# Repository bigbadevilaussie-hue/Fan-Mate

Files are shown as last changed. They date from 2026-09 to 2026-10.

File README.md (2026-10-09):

# Fan-Mate

ESP32-C3 fan controller that keeps an iPhone cool on a 24/7 hotspot mount.

The iPhone is the sole internet uplink (weak signal, rural Queensland). Every byte through the network heats its cellular modem. Fan-Mate watches the router WAN traffic rate and spins a 40mm PWM fan when downloads are detected — before the phone gets hot, not after.

Current: **FW v4.50** · **Tk GUI v4.50** · **QML GUI2 v1.11** (parked)

Repo: https://github.com/bigbadevilaussie-hue/Fan-Mate

## Hardware

| Component | Pin | Notes |
|---|---|---|
| MCU | — | ESP32-C3 SuperMini |
| Thermistor (NTC) | GPIO 0 | 10k MF52AT, room temp, +6.0 offset |
| Hall sensor | GPIO 1 | A3144, phone presence |
| Fan tach | GPIO 3 | INPUT_PULLUP, IRQ |
| DS18B20 | GPIO 4 | Phone back contact |
| OLED SDA / SCL | GPIO 5 / 6 | I2C |
| Fan PWM | GPIO 7 | 25 kHz, 8-bit |
| Blue LED | GPIO 8 | onboard |
| Buzzer | GPIO 10 | LEDC channel 1 |

Shroud printed, mounted on Quad Lock adapter. Phone docked. DS18B20 in the Quad Lock socket against the case back. Fan over the camera bump, adjacent to the SoC.

## What it does

- **Network-triggered boost** — responds to router WAN traffic, not phone temp. Traffic heats the modem before the phone surface warms.
- **Rate-based gears** — target gear = `floor(net_kbps / threshold)`, clamp 0–4, with up/down hysteresis.
- **Cooldown hold** — when traffic stops, holds gear 1 until phone temp returns to the pre-boost value (or 20-min timeout).
- **Delta guard** — phone 5.1°C above room → gear 1 floor. Configurable.
- **Heat control** — four thresholds (Warm/Hot/Hotter/Critical = 33/35/37/39) with per-gear hysteresis.
- **Priority** — `max(heat, delta, boost)`.
- **Kill mode** — at Critical: fan 100%, buzzer every 30s, repeater cut. Manual re-arm.
- **Autonomous** — cools and logs whether the Mac is on or off. Sleeps when phone absent.
- **Hourly log rotation** — sealed, CRC32-verified Mac sync, Drive upload.

## Build

Arduino IDE 2.x or arduino-cli. ESP32 core **2.0.17** (2.x required — do NOT upgrade to 3.x).

Partition: `:PartitionScheme=min_spiffs` (1408 KB LittleFS).

```zsh
arduino-cli compile --fqbn esp32:esp32:esp32c3:PartitionScheme=min_spiffs --export-binaries .
# binary: build/esp32.esp32.esp32c3/fanmate.ino.bin
```

Libraries: Adafruit GFX, Adafruit BusIO, Adafruit SSD1306, OneWire, DallasTemperature, ArduinoJson.

Secrets: copy `secrets.example.h` to `secrets.h`, fill WiFi + Opal credentials.

OTA: Tk GUI menu → 📡 Update Firmware.

## GUI

**Tk GUI** (primary) — `python3 fanmate.py`. Live telemetry, Settings, Reports, DynaTune KPI board, OTA, log sync, weather, day/night theme.

**QML GUI2** (parked) — `fanmate_v2/*`. Ports frozen behaviour once firmware + Tk are stable.

**Web dashboard** — served by ESP32 at `/`. Read-only except kill-mode banner.

## Repo

https://github.com/bigbadevilaussie-hue/Fan-Mate

Related: [Bike-Mate](https://github.com/bigbadevilaussie-hue/Bike-Mate) — ESP32-C3, same OLED fork, same OTA/GitHub-upload pattern. Still on the breadboard. Fan-Mate is the reference implementation; port to Bike-Mate once Fan-Mate is stable.

## Rules

### Version bump
Every change bumps the version, before compiling:

- Firmware: `FAN_MATE_VERSION` in `Config.h`
- Tk: `GUI_VERSION` in `fanmate/config.py`
- QML: `guiVersion` in `fanmate_v2/qml/Main.qml`

If the bump lands after the compile, the firmware reports the old version and log filenames use the old prefix.

### Behaviour
Never mention sleep, rest, breaks, session length, time of day, or "good morning/evening". Do not suggest stopping. Do not wrap up sessions unless asked. Just answer the question and keep working.

### Patching
Write each patch as a Python script using a heredoc into `/tmp/patch.py`, then run it in the same paste:

```zsh
cat > /tmp/patch.py <<'PYEOF'
import os, shutil
...
PYEOF
python3 /tmp/patch.py
```

- Always back up first with `shutil.copy2`.
- Always end with a verification print.
- Patch and run in one block.
- Never paste standalone multi-line shell that edits files.

### Working style
- Don't guess. Read the screenshot, read the file, read the log. If unsure, say unsure.
- Don't score, rate, or editorialise unless asked.
- Don't reference time of day, session length, or wrap-up language.
- One change at a time unless asked for more. Short replies.

### Naming
GUI = Tk (`fanmate/*.py`). GUI2 = QML (`fanmate_v2/*`). Web = `WebPage.h` (needs flash). Firmware = `.cpp`/`.h`/`.ino`.

### Handoff — read this first

The README alone is not enough. Before changing anything, ask for:

- repo.txt, dump.txt, firmware_dump.txt — three dumps written to Desktop. Ask how they were produced.
- ls ~/Documents/Arduino/libraries/Adafruit_SSD1306_72x40/ — custom fork, not in the repo, required to compile.
- git ls-files secrets.h — if it prints anything, credentials in that file are tracked and need rotating.
- Which GUI is the live target. README says QML is parked; recent commits say otherwise. Ask, do not assume.
- If touching DynaTune or log analysis: one log-*.csv and dynatune-history.csv from ~/Documents/FanMate_logs/.

Do not touch code until all three dumps and the library listing are in hand.

### Gotchas
- Catalina mDNS slow. Use IP `192.168.8.242`, not `.local`.
- `WiFi.RSSI()` returns 0 when disconnected.
- `server.handleClient()` doesn't work here. Use `server_loop()`.
- NVS keys ≤15 chars. Longer keys silently fail.
- Fan fails safe to 100% (bootloader leaves GPIO 7 undriven).
- QML Column + anchors don't mix. Use `TapHandler` for clicks inside Columns.

## Known issues

**DynaTune**
- `_test_boost` infers gear from fan %, which fails during night mode (fan 75% reads as gear 3 when the firmware commanded gear 4). Fix: read the row timestamp, check against the night window, adjust the fan→gear mapping.
- `_test_heat_gears` compares `temp.gear1` against `avg_room + delta_trigger`. Recommendation text hardcodes `boost.on_hold 4 → 2` regardless of the current `on_hold` value. Fix: read the current setting and only suggest a change if it differs.

**Firmware**
- Cooldown margin. Currently `cold_temp + 0.3` releases the fan before residual modem heat arrives, so phone can creep up ~1°C post-download. Consider `COOLDOWN_MARGIN_C = 1.5` in AutoBoost.cpp, or make it configurable via NVS (`cooldown.margin`, Settings field).
- Double-Apply in the same minute still creates a duplicate seal name (cosmetic; collision suffix `-2` handles it, GitHub upload succeeds on second attempt with SHA).

**GUI**
- Settings dialog reads `state.latest_config` which refreshes every 5 min. Can show stale values right after an Apply.

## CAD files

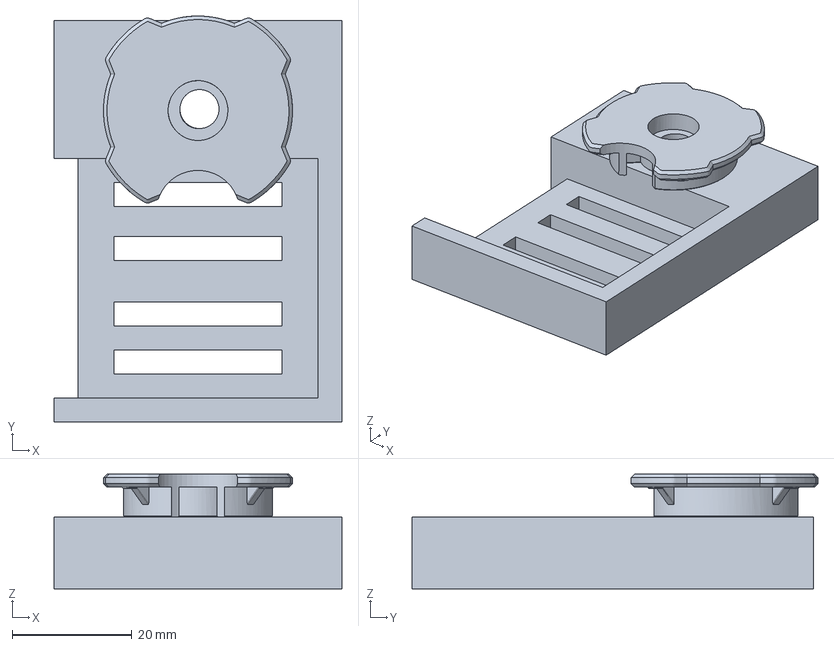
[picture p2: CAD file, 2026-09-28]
3mf/phone-assembly.3mf
48.0 x 67.8 x 19.2 mm

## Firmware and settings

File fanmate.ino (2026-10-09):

#include "Config.h"
#include "Settings.h"
#include "FanController.h"
#include "DisplayManager.h"
#include "WiFiManager.h"
#include "WebServer.h"
#include "OpalClient.h"
#include "AutoBoost.h"
#include "Logging.h"
#include "WeatherClient.h"
#include "SerialBuffer.h"
#include "Songs.h"

#include <esp_arduino_version.h>

#if ESP_ARDUINO_VERSION_MAJOR >= 3
#error "Fan-Mate requires Arduino ESP32 core 2.x (2.0.17)"
#endif

float currentTemp  = 0.0;
int   fanPct       = 0;
int   fanRPM       = 0;
int   alertState   = 0;
bool  phonePresent = false;

volatile bool otaInProgress = false;

SystemState   sys_state = STATE_ACTIVE;
static unsigned long sleep_start_ms = 0;
bool          have_baseline = false;
uint64_t      last_rx       = 0;
unsigned long last_tick     = 0;

#define WEB_HIST_LEN 60
float webTempHist[WEB_HIST_LEN] = {0};
float webNetHist[WEB_HIST_LEN]  = {0};
float webRpmHist[WEB_HIST_LEN]  = {0};
int   webHistIdx = 0;

void enter_sleep() {
    log_print("[SLEEP] phone absent — entering sleep\n");
    log_write_event("SLEEP");
    log_flush_seal();
    sys_state = STATE_LIGHT_SLEEP;
    sleep_start_ms = millis();
    silenceFanAndAlerts();
    auto_boost_release();
    opal_pause();
    clearDisplay();
    digitalWrite(LED_PIN, LOW);
    playNokiaSong();
    log_print("[SLEEP] entered\n");
}

void exit_sleep() {
    sys_state = STATE_ACTIVE;
    log_resume();
    log_write_event("WAKE");
    have_baseline = false;
    last_rx = 0;
    last_tick = millis() - 15000;
    opal_resume();
    wakeDisplay();
    digitalWrite(LED_PIN, HIGH);
    playNokiaSong();
    log_print("[SLEEP] awake\n");
}

void setup() {
    Serial.begin(115200);
    delay(500);

    serial_buf_init();

    Serial.println();
    Serial.println("================================");
    Serial.printf ("  Fan-Mate V%s\n", FAN_MATE_VERSION);
    Serial.printf ("  Build: %s %s\n", __DATE__, __TIME__);
    Serial.println("  Chip:  ESP32-C3");
    Serial.println("  Mode:  HTTP only");
    Serial.println("================================");

    pinMode(LED_PIN, OUTPUT);
    digitalWrite(LED_PIN, HIGH);

    setenv("TZ", "AEST-10", 1);
    tzset();

    settings_load();
    weather_init();
    initHardware();

    Serial.println("[BOOT] waiting for DS18B20...");
    for (int i = 0; i < 20; i++) {
        float t = 0.0f;
        readDS18B20(t);
        if (t > -50.0f && t < 100.0f && t != 0.0f) {
            currentTemp = t;
            log_print("[BOOT] DS18B20 first: %.1f C\n", t);
            break;
        }
        delay(500);
    }
    initDisplay();
    log_init();
    log_write_reset_reason();

    drawSplashScreen();
    delay(5000);

    wifi_setup();

    // v4.29: wait up to 3s for LAN clock before boot recovery
    {
        unsigned long wait_start = millis();
        while (!clock_synced() && millis() - wait_start < 5000) {
            wifi_loop();
            clock_sync();
            delay(200);
        }
        log_print("[BOOT] clock wait done (%s)\n",
                  clock_synced() ? "synced" : "timeout");
    }

    log_boot_recovery();

    log_print("[BOOT] Fan-Mate V%s ready\n", FAN_MATE_VERSION);
}

float lastNetKbps = 0.0;

static void tick_15s() {
    uint64_t rx_now = 0;
    bool opal_ok = opal_poll(rx_now);

    float kbps = 0.0f;
    if (opal_ok) {
        if (have_baseline && rx_now >= last_rx) {
            uint64_t delta = rx_now - last_rx;
            kbps = (delta / 15.0f) / 1024.0f;
        } else {
            have_baseline = true;
        }
        last_rx = rx_now;
    } else {
        // Router unreachable — keep last known rate, skip boost update
        kbps = lastNetKbps;
    }

    static float peak_hist[3] = {0, 0, 0};
    static int   peak_idx = 0;
    peak_hist[peak_idx] = kbps;
    peak_idx = (peak_idx + 1) % 3;

    float kbps_smooth = peak_hist[0];
    if (peak_hist[1] > kbps_smooth) kbps_smooth = peak_hist[1];
    if (peak_hist[2] > kbps_smooth) kbps_smooth = peak_hist[2];

    if (kbps_smooth > 10240.0f) kbps_smooth = lastNetKbps;
    lastNetKbps = kbps_smooth;

    webTempHist[webHistIdx] = currentTemp;
    webNetHist[webHistIdx]  = kbps_smooth;
    webRpmHist[webHistIdx]  = (float)fanRPM;
    webHistIdx = (webHistIdx + 1) % WEB_HIST_LEN;

    auto_boost_update(kbps_smooth, currentTemp, opal_ok);

    if (currentTemp > 0.0) {
        log_write(currentTemp, kbps_smooth,
                  auto_boost_gear(),
                  fanPct, fanRPM);
    }

    log_rotate_check();
    log_check_full();

#if DEBUG_VERBOSE
    log_print("[TICK] temp=%.1f fan=%d%% net=%.1f KB/s boost=%d rpm=%d\n",
              currentTemp, fanPct, kbps_smooth,
              auto_boost_gear(), fanRPM);
#endif
}

void loop() {
  server_loop();
    static unsigned long lastOLED     = 0;
    static bool          server_ready = false;

    unsigned long now = millis();

    wifi_loop();
    clock_sync();
    weather_loop();
    if (wifi_connected() && !server_ready) {
        server_setup();
        opal_init();
        auto_boost_init();
        server_ready = true;
    }
    if (server_ready) {
        server_loop();
    }

    updatePhoneDetection();
    updateTach();
    readDS18B20(currentTemp);

    bool phone_now = phonePresent;

    if (sys_state == STATE_ACTIVE) {
        if (!phone_now &&
            phone_absent_since > 0 &&
            now - phone_absent_since >= PHONE_SLEEP_DELAY_MS) {
            enter_sleep();
        }
    } else if (sys_state == STATE_LIGHT_SLEEP) {
        if (phone_now &&
                   phone_present_since > 0 &&
                   now - phone_present_since >= PHONE_WAKE_DELAY_MS) {
            exit_sleep();
        }
    }

    beep_once_update();

    if (sys_state == STATE_ACTIVE) {
        updateFanAndAlerts(currentTemp, fanPct, fanRPM, alertState, phonePresent);

        if (now - lastOLED >= 500 && !otaInProgress) {
            lastOLED = now;
            updateDisplay(currentTemp, fanPct, fanRPM, alertState, phonePresent);
        }

        if (server_ready && now - last_tick >= 15000) {
            last_tick = now;
            tick_15s();
        }
    }
}

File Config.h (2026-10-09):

#ifndef CONFIG_H
#define CONFIG_H

#if __has_include("secrets.h")
    #include "secrets.h"
#else
    #warning "secrets.h not found - copy secrets.example.h to secrets.h"
    #include "secrets.example.h"
#endif

// v4.28 network resilience
#define OPAL_HTTP_TIMEOUT_MS 400
#define OPAL_RSSI_FLOOR -70
#define NTP_SYNC_COOLDOWN_MS 60000
#define CLOCK_SYNC_INTERVAL_MS  60000UL
#define CLOCK_HTTP_TIMEOUT_MS   3000

enum SystemState {
    STATE_ACTIVE      = 0,
    STATE_LIGHT_SLEEP = 1,
};
extern SystemState   sys_state;
extern unsigned long phone_absent_since;

#define FAN_MATE_VERSION "4.60"

#define DEBUG_VERBOSE 0

#define SDA_PIN          5
#define SCL_PIN          6
#define FAN_PWM_PIN      7
#define LED_PIN          8
#define BUZZER_PIN       10
#define BUZZER_TONE_HZ   2000
#define TACH_PIN         3
#define DS18B20_PIN      4
#define PHONE_SENSE_PIN  1
// v4.60: hall sensor temporarily disabled (shorted VCC/GND)
// Set to 1 once the wiring is fixed. When 0, phonePresent is
// forced true so the device never enters light sleep.
#define HALL_SENSOR_ENABLED 0
#define NTC_PIN          0

#define PWM_FREQ      25000
#define PWM_RES       8

#define FAN_STALL_ENABLED 1


#define WARNING_BEEPS       2
#define WARNING_BEEP_MS     150
#define WARNING_GAP_MS      200
#define WARNING_INTERVAL_MS 120000

#define PANIC_BEEPS       5
#define PANIC_BEEP_MS     200
#define PANIC_GAP_MS      200
#define PANIC_INTERVAL_MS 120000

#define KILL_BEEPS       3
#define KILL_BEEP_MS     200
#define KILL_GAP_MS      200
#define KILL_INTERVAL_MS 30000

#define HTTP_PORT                80
#define WIFI_CONNECT_TIMEOUT_MS  15000
#define WIFI_RETRY_INTERVAL_MS   30000

#define SERIAL_BUF_LINES        20
#define PHONE_SLEEP_DELAY_MS    30000UL
#define PHONE_WAKE_DELAY_MS      5000UL
#define OPAL_LOGIN_REFRESH_MS   3000000

#define LOG_SEAL_MIN_ROWS        3
#define LOG_PAUSE_FREE_BYTES     (100 * 1024)
#define LOG_FILENAME_PREFIX      "log-"
#define CONFIG_FILENAME_PREFIX   "config-"
#define CONFIG_HEADER            "timestamp,key,value"
#define LOG_HEADER               "timestamp,temp_c,net_kbps,boost,fan,rpm,event,outdoor_c,room_c"
#define LOG_FILE_LIVE            "/log.csv"
#define LOG_MAX_SEALED           64
#define LOG_KEEP_MIN             8

#define DRIVE_UPLOAD_TIMEOUT_MS  15000

#define NVS_LOG_NS               "log"
#define NVS_LOG_START_KEY        "live_start"

#endif

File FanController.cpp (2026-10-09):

#include "FanController.h"
#include "Config.h"
#include "Settings.h"
#include "AutoBoost.h"
#include "Logging.h"
#include "SerialBuffer.h"
#include "Songs.h"
#include "OpalClient.h"

#include <OneWire.h>
#include <DallasTemperature.h>

static OneWire oneWire(DS18B20_PIN);
static DallasTemperature ds18b20(&oneWire);

static int  fanPWM       = 0;
static int  fanPctLocal  = 0;
static int  fanRPMLocal  = 0;
static int  alertLevel   = 0;
extern bool phonePresent;

static volatile unsigned long tachPulses   = 0;
static unsigned long          lastTachRead = 0;

static unsigned long lastAlertStart = 0;
static int           beepIndex      = 0;
static bool          beepActive     = false;
static unsigned long beepTimer      = 0;

static bool          tempConversionRunning = false;
static unsigned long tempConversionStart   = 0;

// Boost/heat state
static int lastFanGear  = -1;

// Delta guard state — enter at 5.0, exit at 4.0 (hysteresis)
static bool delta_guard_active = false;

// Heat gear state — stateful so each gear has entry/exit hysteresis
static int heat_gear_state = 0;

// Stall detection
static unsigned long fan_stall_since = 0;
static bool          fan_stall_alarm = false;

// Phone presence timestamps (v4.06)
unsigned long phone_absent_since  = 0;
unsigned long phone_present_since = 0;

// Kill mode (v4.00)
enum KillState { KILL_AUTO = 0, KILL_ACTIVE = 1, KILL_OFF = 2 };
static KillState killState = KILL_AUTO;
static volatile bool kill_clear_requested = false;
static volatile bool kill_auto_requested  = false;

// ------------------------------------------------------------
//  Forward declarations
// ------------------------------------------------------------
static void kill_state_machine(float currentTemp);
static void runBeepSequence(int beeps, int beepMs, int gapMs, int intervalMs);
static void beep_once();
void beep_once_update();

// ------------------------------------------------------------
void readDS18B20(float &currentTemp) {
    unsigned long now = millis();
    static unsigned long lastStart = 0;
    if (!tempConversionRunning && now - lastStart >= 2000) {
        lastStart = now;
        ds18b20.requestTemperatures();
        tempConversionRunning = true;
        tempConversionStart = now;
        return;
    }
    if (tempConversionRunning && now - tempConversionStart >= 750) {
        float t = ds18b20.getTempCByIndex(0);
        tempConversionRunning = false;
        if (t == DEVICE_DISCONNECTED_C || t == 0.0 || t < -50.0f || t > 100.0f) {
            Serial.printf("[DS18B20] bad read: %.1f - keeping last\n", t);
            return;
        }
        currentTemp  = t;
    }
}

float readNTC() {
    long sum = 0;
    for (int i = 0; i < 4; i++) {
        sum += analogRead(NTC_PIN);
        delayMicroseconds(50);
    }
    int raw = sum / 4;
    if (raw <= 0 || raw >= 4095) return -99.0f;
    float v_out = raw * (3.3f / 4095.0f);
    float r_ntc = 10000.0f * (v_out / (3.3f - v_out));
    float steinhart = log(r_ntc / 10000.0f) / 3950.0f;
    steinhart += 1.0f / 298.15f;
    float temp_c = (1.0f / steinhart) - 273.15f;
    return temp_c + 6.0f;  // calibration offset
}

void updatePhoneDetection() {
#if !HALL_SENSOR_ENABLED
    // Hall sensor disconnected. Force phone present so the device
    // never enters light sleep and the fan runs autonomously.
    static bool reported = false;
    if (!reported) {
        reported = true;
        phonePresent = true;
        phone_present_since = millis();
        phone_absent_since = 0;
        log_print("[PHONE] sensor disabled, forcing present\n");
    }
    return;
#endif
    static bool lastState = false;
    static unsigned long lastChange = 0;
    static bool initialized = false;
    bool present = (digitalRead(PHONE_SENSE_PIN) == LOW);

    if (!initialized) {
        initialized = true;
        lastState = present;
        phonePresent = present;
        if (present) {
            phone_present_since = millis();
        } else {
            phone_absent_since = millis();
        }
        log_print("[PHONE] initial: %s\n", present ? "present" : "absent");
        return;
    }

    if (present != lastState) {
        unsigned long now = millis();
        if (now - lastChange > 500) {
            lastState = present;
            lastChange = now;
            phonePresent = present;
            if (present) {
                phone_present_since = now;
                phone_absent_since  = 0;
            } else {
                phone_absent_since  = now;
                phone_present_since = 0;
            }
            log_print("[PHONE] %s\n", present ? "detected" : "removed");
        }
    }
}

// ------------------------------------------------------------
static int compute_temp_gear(float t) {
    // Stateful ladder with hysteresis on both entry and exit.
    // Entry at each threshold; exit at threshold - tempHysteresis.
    float h = config.tempHysteresis;

    if (heat_gear_state >= 4) {
        if (t >= config.tempGear4 - h) return 4;
    } else if (t >= config.tempGear4) return 4;

    if (heat_gear_state >= 3) {
        if (t >= config.tempGear3 - h) return 3;
    } else if (t >= config.tempGear3) return 3;

    if (heat_gear_state >= 2) {
        if (t >= config.tempGear2 - h) return 2;
    } else if (t >= config.tempGear2) return 2;

    if (heat_gear_state >= 1) {
        if (t >= config.tempGear1 - h) return 1;
    } else if (t >= config.tempGear1) return 1;

    heat_gear_state = 0;
    return 0;
}

// ------------------------------------------------------------

// ------------------------------------------------------------
static bool          short_beep_active = false;
static unsigned long short_beep_timer  = 0;

static void beep_once() {
    if (short_beep_active) return;
    tone(BUZZER_PIN, BUZZER_TONE_HZ);
    short_beep_active = true;
    short_beep_timer  = millis();
}

void beep_once_update() {
    if (short_beep_active && millis() - short_beep_timer >= 80) {
        noTone(BUZZER_PIN);
        short_beep_active = false;
    }
}
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

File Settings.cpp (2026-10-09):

#include "Settings.h"
#include "Config.h"
#include "SerialBuffer.h"
#include "Logging.h"

#include <Preferences.h>
#include <ArduinoJson.h>
#include <time.h>

FanMateConfig config;
static Preferences prefs;

static void set_defaults() {
    config.tempGear1      = 30.0;
    config.tempGear2      = 32.0;
    config.tempGear3      = 34.0;
    config.tempGear4      = 36.0;
    config.tempHysteresis = 1.0;
    config.deltaTrigger   = 5.1;



    config.boostThreshold = 900;
    config.boostOnHold    = 2;
    config.boostOffHold   = 4;
}

void settings_load() {
    set_defaults();
    prefs.begin("fanmate", true);

    config.tempGear1 = prefs.getFloat("temp.gear1",
                        prefs.getFloat("temp.warning", config.tempGear1));
    config.tempGear2 = prefs.getFloat("temp.gear2",
                        prefs.getFloat("temp.panic",   config.tempGear2));
    config.tempGear3 = prefs.getFloat("temp.gear3",
                        prefs.getFloat("temp.kill",    config.tempGear3));
    config.tempGear4 = prefs.getFloat("temp.gear4",
                        prefs.getFloat("temp.kill",    config.tempGear4));
    config.tempHysteresis = prefs.getFloat("t.hyst", config.tempHysteresis);
    config.deltaTrigger   = prefs.getFloat("delta.trigger", config.deltaTrigger);



    config.boostThreshold = prefs.getInt("boost.thr", config.boostThreshold);
    config.boostOnHold    = prefs.getInt("boost.on",  config.boostOnHold);
    config.boostOffHold   = prefs.getInt("boost.off", config.boostOffHold);

    prefs.end();

    Serial.println("[CFG] loaded:");
    Serial.printf("  temp warm=%.1f hot=%.1f hotter=%.1f crit=%.1f hyst=%.1f\n",
                  config.tempGear1, config.tempGear2, config.tempGear3,
                  config.tempGear4, config.tempHysteresis);
    Serial.printf("  boost thr=%d on=%d off=%d\n",
                  config.boostThreshold, config.boostOnHold, config.boostOffHold);
}

void settings_save() {
    prefs.begin("fanmate", false);

    prefs.putFloat("temp.gear1",       config.tempGear1);
    prefs.putFloat("temp.gear2",       config.tempGear2);
    prefs.putFloat("temp.gear3",       config.tempGear3);
    prefs.putFloat("temp.gear4",       config.tempGear4);
    prefs.putFloat("t.hyst",  config.tempHysteresis);
    prefs.putFloat("delta.trigger", config.deltaTrigger);



    prefs.putInt("boost.thr", config.boostThreshold);
    prefs.putInt("boost.on",  config.boostOnHold);
    prefs.putInt("boost.off", config.boostOffHold);

    prefs.end();
    Serial.println("[CFG] saved");
}

void settings_reset() {
    prefs.begin("fanmate", false);
    prefs.clear();
    prefs.end();
    set_defaults();
    Serial.println("[CFG] reset");
}

void settings_apply_json(const char* json) {
    StaticJsonDocument<2048> doc;
    DeserializationError err = deserializeJson(doc, json);
    if (err) { Serial.printf("[CFG] JSON fail: %s\n", err.c_str()); return; }

    if (doc.containsKey("reset")) { settings_reset(); return; }

    if (doc.containsKey("temp")) {
        JsonObject t = doc["temp"];
        if (t.containsKey("gear1"))      config.tempGear1 = t["gear1"].as<float>();
        else if (t.containsKey("warning")) config.tempGear1 = t["warning"].as<float>();
        if (t.containsKey("gear2"))      config.tempGear2 = t["gear2"].as<float>();
        else if (t.containsKey("panic"))   config.tempGear2 = t["panic"].as<float>();
        if (t.containsKey("gear3"))      config.tempGear3 = t["gear3"].as<float>();
        if (t.containsKey("gear4"))      config.tempGear4 = t["gear4"].as<float>();
        else if (t.containsKey("kill"))    config.tempGear4 = t["kill"].as<float>();
        if (t.containsKey("hysteresis")) config.tempHysteresis = t["hysteresis"].as<float>();
        if (t.containsKey("delta_trigger")) config.deltaTrigger = t["delta_trigger"].as<float>();
    }


    if (doc.containsKey("boost")) {
        JsonObject b = doc["boost"];
        if (b.containsKey("threshold")) config.boostThreshold = b["threshold"].as<int>();
        if (b.containsKey("on_hold"))   config.boostOnHold    = b["on_hold"].as<int>();
        if (b.containsKey("off_hold"))  config.boostOffHold   = b["off_hold"].as<int>();
    }

    settings_save();

    log_seal_now();
    log_write_config_snapshot();
    log_write_event("CFG_APPLIED");

    Serial.println("[CFG] applied + saved");
}

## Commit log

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2026-09-24 V2.03: splash, OTA debug, MTU fix, OLED bars
    [Config.h, DisplayManager.cpp, fanmate.ino]
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2026-09-25 V3.43: serial format fixes, pre-reboot events, GUI menu cleanup
    [Config.h, fanmate.ino]
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2026-09-25 V3.44: dashboard version fix, host flag, GUI graph scale + OTA improvements
    [Config.h]
2026-09-26 V3.45.2: TZ fix, sleep state machine, config flatten
    [Config.h, DisplayManager.cpp, OpalClient.cpp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]
2026-09-26 GUI v3.46: heat control section, boost thresholds 700/400, no test_delay, STATUS card, car boosting
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2026-09-26 V3.71: AutoBoost hysteresis, GUI settings redesign, remove LOG_MAX_SIZE
    [Config.h, DisplayManager.cpp]
2026-09-26 V3.72: NTP loop wired, fan stall alarm, quiet serial, GUI cleanup
    [Config.h, DisplayManager.cpp, FanController.cpp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]
2026-09-26 V3.73: serial buffer refactor, log event routing, stall gated, report x-axis
    [Config.h, FanController.cpp, WiFiManager.cpp]
2026-09-26 V3.74: route fan/boost events through serial buffer, fix log time-jump recovery
    [Config.h, FanController.cpp]
2026-09-26 GUI: add Daily report, HTTP timeout 10s, quiet connected print, section markers
2026-09-27 V3.81: quiet hours, stall alarm enabled, web graph axes
    [Config.h, FanController.cpp]
2026-09-27 feat: implement thermal Kill Mode with persistent loop freeze, OLED lock, and 30s buzzer alert
    [Config.h, OpalClient.cpp, fanmate.ino]
2026-09-27 Fix: call opal_set_repeater(false) on Kill alert
    [FanController.cpp]
2026-09-28 hardware: add phone assembly 3MF
    [phone-assembly.3mf]
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2026-09-28 v3.95: log eviction, real event values, comma sanitize, opal bail fix, room_c column
    [Config.h, fanmate.ino]
2026-09-28 v4.00: buzzer tone fix, kill state machine, web kill endpoints
    [Config.h, FanController.cpp]
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2026-09-28 v4.02: log polish — seal min rows 3, cached free bytes, opal-aware events
2026-09-28 v4.03: boot recovery after NTP, OPAL diagnostics, sealed cap fix, weather timing, config validation
    [Config.h, OpalClient.cpp, fanmate.ino]
2026-09-28 v4.05: fan LEDC channel 2 fix, OPAL login diagnostics
    [Config.h, FanController.cpp, OpalClient.cpp]
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2026-09-28 gui v3.77: DynaTune dual-axis graph, ZZZ night fan, boost start temp note
2026-09-28 handoff: sleep/wake issues deferred to hall sensor arrival
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2026-09-29 v4.11 / gui-v3.82 / gui-v2-v1.07: heat control renamed to four gear thresholds (Warm/Hot/Hotter/Critical)
2026-09-29 v4.12 / gui-v3.84: boost_lvl reports data_gear (0 during cooldown), cooling flag in /status; Tk layout rework
    [Config.h]
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2026-09-30 v4.14: NTC +6.0 offset, fan kick-start, interrupt-safe tach; gui-v3.85 room column + footer
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2026-09-30 v4.16 / gui-v3.86: phoneMode removed (always auto-detect via hall); Nokia tune; NTC + hall wired and verified
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2026-09-30 v4.17: phonePresent extern shadow fix; Nokia jingle on sleep/wake
    [Config.h, FanController.cpp, fanmate.ino]
2026-09-30 v4.18: delta guard (phone-room > 5C -> gear 1 + WARN), flat PWM map (gear 1 = 25%), kick-start 400ms
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2026-09-30 gui-v3.89: DynaTune KPI board (6 tests) + dynatune.py module + event column parsers + room temp on plots + FANMATE_URL IP
2026-09-30 v4.20: WebServer /config valid JSON — remove stray {} and trailing comma after night block
2026-09-30 docs: add AUDIT.md — five-AI desk check consolidated, 97 findings + not-a-bug list
2026-09-30 v4.21: hysteresis for delta guard (5.0->4.0) and heat gears; cosmetic cleanup (dead macros, stale comments, unused vars)
2026-10-01 docs: AUDIT.md — mark 10 items fixed in v4.21
2026-10-01 v4.22: NVS boost keys shortened to fit 15-char limit — boost config persists across reboot
    [Config.h, Settings.cpp]
2026-10-01 docs: AUDIT.md — #2 NVS key length fixed in v4.22
2026-10-01 gui-v3.90: correct version drift — code was still 3.87 while gui-v3.89 tag existed
2026-10-01 gui-v3.91: DynaTune fixes (7), GUI robustness (5), reports fixes (2) — KPI board now honest
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2026-10-01 v4.24: rate cap 10MB/s, log actual gear, non-blocking kick-start, orphan preserve, evict sort
2026-10-02 gui-v3.92: SettingsDialog fetches config off main thread — no more 10s freeze
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2026-10-02 docs: AUDIT.md — mark 25 findings fixed in v4.21-v4.24 / gui-v3.90-v3.95
2026-10-02 v4.25: Drive upload — sealed logs POST to Apps Script on seal, 302 treated as success
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2026-10-02 v4.27: silence beeps for gear 0-1, alert level 1, and all returns to zero; beep only on 2+ to 2+ transitions
2026-10-07 gui-v4.14: DynaTune rewrite + settings filter + O(n) lag test
    - _test_lag: O(n^2) -> O(n) with deques. 14k rows: ~6min -> <1s
    - DynaTune: pretty layout, IDLE folded into PASS, theme-aware
    - Settings filter: skip whole log files before newest config timestamp
    - Async log load (threading.Thread + root.after)
    - Fast _parse: str.split + slice datetime
    - Settings dialog: treat POST read-timeout as success
    - GUI_VERSION catch-up: 4.06 -> 4.14 (footer drift; code was ahead)
2026-10-07 fw v4.50: configurable delta trigger + RPM clamp
    - deltaTrigger field in FanMateConfig, default 5.1
    - NVS key delta.trigger (11 chars)
    - settings_apply_json reads temp.delta_trigger
    - FanController uses config.deltaTrigger (enter) and
    config.deltaTrigger - 1.0 (exit) instead of hardcoded 5.0/4.0
    - updateTach clamps RPM at 10000 to reject tick-stretch artefacts
    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
2026-10-07 gui-v4.50: Tk matches Web, Delta trigger setting, heat threshold check
    - _tick_body now renders alert / stall / sleep / opal / boost states
    that were read but never used, matching Web dashboard behaviour
    - Temp graph threshold line uses live temp_warning (gear2), not gear1
    - Graph axes aligned to Web (net 0-8192, temp 15-45)
    - Delta trigger field in Settings dialog, in temp block of /config POST
    - state.py latest_config includes delta_trigger default 5.1
    - DynaTune _test_heat_gears compares temp.gear1 against
    avg_room + delta_trigger; WARNs if diff > 1.5
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2026-10-07 fw v4.51 + gui v4.52: GitHub uploads for logs, config, firmware
    - Logging.cpp: upload_to_drive() -> upload_to_github()
    mbedtls base64, PUT to Fan-Mate-Uploads/logs/YYYY-MM/
    - Config snapshots go to Fan-Mate-Uploads/config/YYYY-MM/
    - Tk GUI _ota_worker: PUT .bin to Fan-Mate-Uploads/firmware/
    Reads GITHUB_TOKEN/OWNER/REPO/BRANCH from secrets.h
    - Config.h: FAN_MATE_VERSION 4.51
    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
2026-10-07 fw v4.52: seal collision handling + GitHub SHA lookup
    - seal_live(): append -2, -3, ... before .csv if name exists.
    Fixes double-Apply overwriting a pending seal in the same minute.
    - upload_to_github(): GET existing file SHA before PUT.
    Update path now returns 200 instead of failing with 422.
    - Config.h: FAN_MATE_VERSION 4.52
    [Config.h]
2026-10-07 gui v4.55: Settings History window (Reports menu)
    New fanmate/changelog.py:
    - CURRENT SETTINGS: snapshot of newest config-*.csv
    - CHANGES: diffs between consecutive snapshots, reason matched
    to nearest earlier dynatune-history.csv run
    - CURRENT RECOMMENDATIONS: newest run's recs + streak count
    - Reports menu -> Settings History
    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
2026-10-07 docs: known issues section
    - Remove night mode (next version)
    - DynaTune night mode gear inference
    - DynaTune heat gear tolerance + stale recommendation text
    - Settings dialog stale config
2026-10-07 docs: known issues — cooldown margin, DynaTune filter, night mode removal
2026-10-08 fw v4.53 + gui v4.56: remove night mode
    DynaTune inferred gear from fan %, so a night-capped gear 4 read as
    gear 3 and raised a false WARN. Removing night mode makes fan % and
    gear match exactly.
    - Config.h: drop QUIET_START_HOUR / QUIET_END_HOUR, version 4.53
    - Settings.h/.cpp: drop nightStart/nightEnd/nightMax, settings_is_night()
    - FanController.cpp: drop quiet_hours() and the fan output cap
    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
2026-10-08 fw v4.54: fix trailing comma in /config JSON
    The night block removal left an orphaned comma after the boost
    close, producing invalid JSON. Any parser rejected it and fell
    back to defaults, causing false HEAT warnings in DynaTune.
    - WebServer.cpp: line 181 "}," -> "}"
    - Config.h: FAN_MATE_VERSION 4.53 -> 4.54
    [Config.h]
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2026-10-09 fw v4.56 + gui v4.58 + qml v1.12: rpm_hist telemetry + graph prep
    Firmware:
    - Add webRpmHist[60] filled in tick_15s
    - Expose rpm_hist in /status
    - WebPage.h: remove graphs, poll 15s
    - Config.h: 4.55 -> 4.56
    Tk GUI:
    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
2026-10-09 qml: TempBar and TEMP lamp — grey/yellow/orange/red/deep-red
    - Normal grey, Warm yellow, Hot orange, Hotter red, Critical deep-red
    - Matches heat gear thresholds (33/35/37/39)
    - Delta guard lights Warm slot orange (distinct from heat)
    - StatusLamps TEMP lamp uses same palette
2026-10-09 fw v4.58: serial page cleanup + OTA chunk progress
    - Config.h: SERIAL_BUF_LINES 50 -> 20
    - Config.h: FAN_MATE_VERSION 4.57 -> 4.58
    - WebServer.cpp: /serial page strips title + dashboard link,
    100% height, reduced padding, auto-scroll
    - WebServer.cpp: [OTA] downloading NNN KB every 128 KB
    - WebServer.cpp: [OTA] done: N bytes, rebooting
    [Config.h]
2026-10-09 qml: full OTA flow with serial handoff
    - bridge.py: otaDone signal, _ota_worker archives locally, uploads
    .bin to GitHub, POSTs to device, waits for reboot, emits otaDone
    - main.py: QtWebEngineQuick.initialize()
    - Main.qml: Serial menu item opens internal WebEngine panel; zoomFactor
    1.15; onOtaDone opens serial panel after reboot
    - OtaDialog.qml: onOtaDone closes dialog
2026-10-09 qml: TEMP lamp off at idle (was always lit green)
    - Idle (temp_lvl=0, alert=0): off
    - Delta guard (alert=1): orange
    - Heat gear 1-4: yellow/orange/red/deep-red
    - Label dims at idle
2026-10-09 qml: OtaDialog sizing — 340 wide, padding on Dialog not Column
    Column.padding shifts children but doesn't shrink parent.width,
    so children using width: parent.width overflow by the padding
    amount. Move padding to the Dialog itself, center buttons via x.
2026-10-09 qml: open serial panel at upload start, byte progress in dialog
    - bridge.py: otaUploading signal emitted before device POST
    - bridge.py: MultipartEncoderMonitor reports progress every 128 KB
    - Main.qml: serial panel opens on otaUploading, not otaDone
2026-10-09 qml: TrafficGauge repeaters derived from vmax
    Hardcoded [1,2,3,4] and [0.5,1.5,2.5,3.5] arrays clashed with vmax:3.
    The 4 and 3.5 clamped onto the 3 position, stacking labels.
    - major ticks/labels: model = Math.floor(vmax), value = index + 1
    - minor ticks: model = Math.floor(vmax), value = index + 0.5
2026-10-09 qml: TempGauge ticks derived from vmin/vmax
    Hardcoded [20,25,30,35] and [18,22.5,...,37.5] didn't follow the
    scale when tempGear4 changed (vmax = tempGear4 + 2). The 18 minor
    also sat exactly on vmin, on top of the track's round cap.
    - tickStep = 5, firstTick = ceil(vmin/step), tickCount = floor((vmax-vmin)/step)
    - majors: v = (firstTick + index) * step
    - minors: v = major + step/2, visible only if v < vmax
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2026-10-09 qml: lazy serial WebEngine, fixed bottom cells, footer fallback
    - WebEngineView url bound to serialPanel.visible
    - Bottom row cells fixed 64px wide
    - Footer falls back to ? if dev.fw undefined
    - Serial header spacer 320 -> 340
    - Drawer spacer deleted
2026-10-09 fw v4.59 + gui v4.59: delta_trigger in snapshot, schema-safe diff
    - Logging.cpp: log_write_config_snapshot writes temp.delta_trigger
    - changelog.py: only diff keys present in both files (intersection),
    so old-vs-new schema drift doesn't list phantom changes
    - Config.h: FAN_MATE_VERSION 4.58 -> 4.59
    - fanmate/config.py: GUI_VERSION 4.58 -> 4.59
    [Config.h]
2026-10-09 Revert "qml: style pass — fonts, offsets, zone colors"
    This reverts commit d95a4f61b4bb3c50bc09596c70c13c60370a630c.
2026-10-09 fw v4.60: hall sensor disable flag
    HALL_SENSOR_ENABLED 0 forces phonePresent=true. Device never
    enters light sleep. Set back to 1 once the A3144 replacement
    is fitted with sleeved legs and a rigid mount.
    - Config.h: HALL_SENSOR_ENABLED 0, version 4.59 -> 4.60
    - FanController.cpp: updatePhoneDetection() early-returns when
    disabled, sets phonePresent=true, logs once
    [Config.h, FanController.cpp]
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2026-10-09 qml: tighten gauge cluster
    - Gauge bounding boxes shrunk (140/190/140), rArc offsets adjusted
    to keep visible sizes the same
    - NET/PHONE gauges pinned to RpmGauge.x, gaps closed
    - BoostBar/TempBar pinned to their gauges
    - Ticks moved outside the arc, shorter, brighter minors
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2026-10-09 qml: drawer — Reports collapsible, Dyna Tune, drop Dashboard
    - Reports: one header with chevron, four children slide out
    - Dyna Tune item added between Reports and Firmware
    - Update Firmware label shortened to Firmware
    - Fan-Mate title removed, drawer width 200 -> 150
    - Dashboard item removed
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2026-10-11 build: strip QtWebEngine for standalone Nuitka build
    - .gitignore: ignore main.dist/ main.build/ main.onefile-build/
    - main.py: remove QtWebEngineQuick import and initialize()
    - Main.qml: remove QtWebEngine import, stub WebEngineView
    Serial panel in QML now shows a placeholder. Re-enable WebEngine
    once the Nuitka codesign bug is fixed and the helper framework
    bundles correctly.
2026-10-11 qml: standalone .app via PyInstaller
    - Fan-Mate-QML.spec: PyInstaller spec, WebEngine excluded
    - main.py: sys._MEIPASS path for frozen bundle, WebEngine removed
    - Main.qml: WebEngineView stubbed, brace cleanup on serial panel
    - README: QML build section, Nuitka bug writeup
2026-10-11 qml: DynaTune panel
    - dynatune_model.py: Tk-free builder, wraps fanmate.dynatune.analyse
    - DynaTunePanel.qml: fullscreen overlay, verdict card, section chips,
    issues + recommendations, worker-thread load
    - bridge.py: dynaTune / dynaTuneLoading properties, loadDynaTune slot,
    _dynaTuneReady signal for GUI-thread handoff
    - Main.qml: Dyna Tune menu item opens the panel
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2026-10-16 fw v4.64: HB to OSA via GET, avoids ESP32 HTTPClient POST body loss
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2026-10-16 cleanup: remove stray logs pushed to wrong repo (moved to Fan-Mate-Uploads)
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
